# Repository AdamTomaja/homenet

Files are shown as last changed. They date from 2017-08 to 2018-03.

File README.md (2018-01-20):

# Home-Net
What is Home-Net? Home-Net is a project which will make Your Home Smart :) 
With Home-Net You can script Your devices in JavaScript and Control them from WEB.

# Screenshots
## Home-Net: Main Page
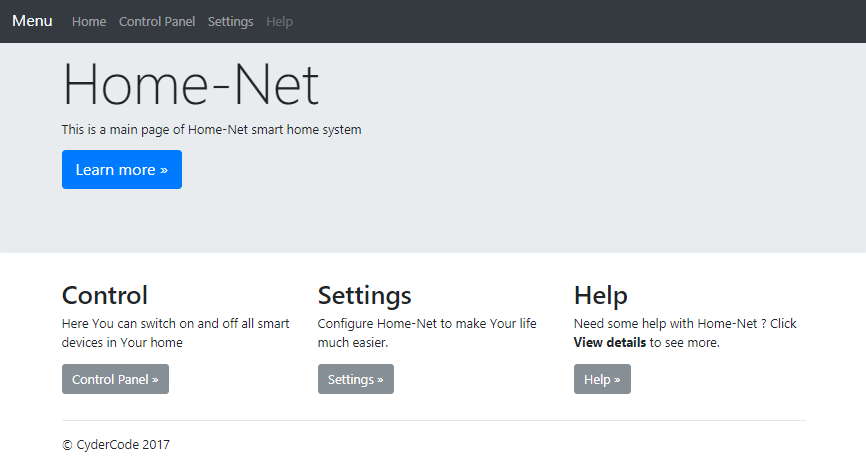
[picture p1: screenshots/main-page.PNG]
Main Page Home-Net Landing Page


## Home-Net: Control Panel
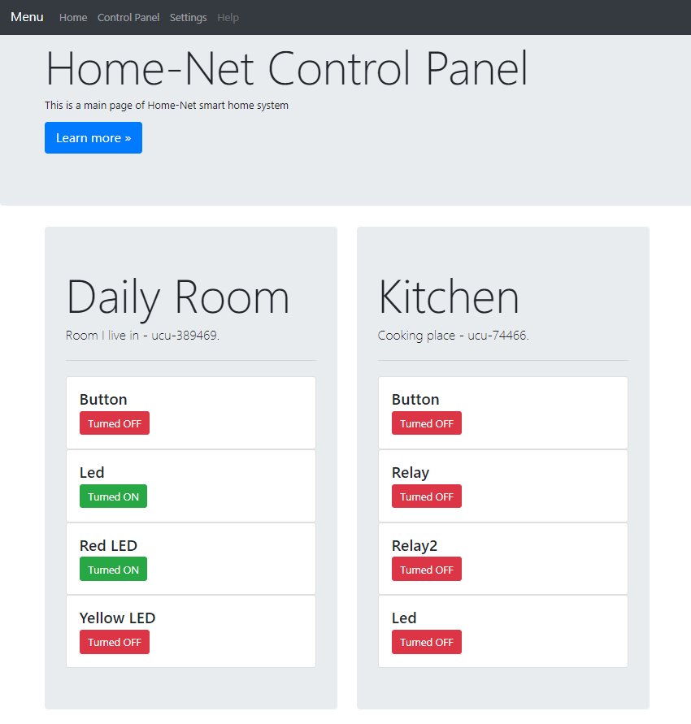
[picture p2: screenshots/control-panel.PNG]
Main Page Home-Net Control Panel


# Configuring system and running UMU
## Network Configuration
MQTT Broker has to be configured with static IP.
To do this, please reconfigure Your /etc/dhcpcd.conf file as follows:

```bash
interface wlan0
static ip_address 192.168.0.10/24
static routers=192.168.0.1
static domain_name_servers=127.0.0.1 8.8.8.8 8.8.4.4
```

## TimeZone Configuration
Please remember to set Your timezone on Linux where UMU is installed. 
This is important because You can use time in Javascript flows. 
For example hour is used to determine if turn lights on when motion is detected.

```bash
sudo dpkg-reconfigure tzdata
```

## Start MQTT broker
Please a compatible MQTT broker for the homenet infrastructure. 
I suggest to use Mosquitto. 
You can run install it and run using following command: 

```bash
service mosquitto start
```

## Install Grafana and Influx DB
* Install InfluxDB
```bash
apt-get install influxdb
```

* Check the status of grafana service
```bash
service influxd status
```
You can also open web interface of influxdb: **http://host:8083**

* Install and start the Grafana
```bash
apt-get install grafana
service grafana-server start
```

* Check the status of Grafana **http://host:3000**

## Run UMU server
Execute following command in **homenet-server** directory
```bash
maven spring-boot:run
```

# MQTT Topics
This is description of MQTT topics used by HomeNet UCU and UMU. 

| Topic name | Description | Message class |
|---|---|---|
| /ucu/gpio/configure | configure gpio direction, input output pullup | ConfigureGpioMessage |
| /ucu/gpio/set | set value for gpio on ucu | SetGpioValueMessage  |
| /umu/gpio/set | gpio value changed on ucu | SetGpioValueMessage  |
| /ucu/hello | request to all ucus to send message to umu with instance names | HelloMessage |
| /umu/hello | all ucus can introduce themselfs to umu | HelloMessage |
| /umu/error | ucu sends to this topic information about errors | ErrorMessage |
| /umu/ping | ucus sends ping message as answer for ping message from umu | PingMessage |
| /ucu/ping | umu send ping request to all ucus | PingMessage |

# UCU Connector
| Signal | Wire Color | Connector Pin |
|---|---|---|
| 5V | Red | 1 |
| 3.3V | White | 2 |
| IO | Blue | 3 |
| GND | Black | 4 |

# LCU - Light Control Unit - Specification
* One 230V Relay output
* Integrated 5V Power Supply
* External Reset Button - in case of BUGs in software
* External MicroUSB port - for programming
* Fixed to wall like normal light switch - using metal frame from common light switch
* External BLS 2x2 Ports for additional sensors and devices `(GND, 5V, 3.3V, GPIO)`
* Fallback to direct power to light

### NodeMCU Pin Capabilities
| IO Index  | Esp8266 pin | OUTPUT | INPUT | Function |
|---|---  |---|---|---|
| 0 | Gpio16 | X | --- (USER Led) | Notification LED  |
| 1 | Gpio5 | X | X | IO0 |
| 2 | Gpio4 | X | X | IO1 |
| 3 | Gpio0 | X | X (Flash Button)  | IO2 | 
| 4 | Gpio2 | X | X | IO3 |
| 5 | Gpio14 | X | X | IO4 | 
| 6 | Gpio12 | X | X | IO5 |
| 7 | Gpio13 | X | X | IO6 |
| 8 | Gpio15 | X | X/2 BOOT,NOPULLUP | Relay |
| 11 - SD2  | Gpio9 | X | X | Button A |
| 12 - SD3  | Gpio10 | X | X | Button B |
| A0 | ADC0 | --- | --- | IO8 |

# UMU Configuration
```json
{
  "mqtt": {
    "host": "rpi-umu",
    "port": 1883
  },
  "instances": [
    {
      "id": "ucu-389469",
      "name": "Daily Room",
      "description": "Room I live in",
      "gpios": [
        {
          "name": "Button",
          "mode": "INPUT",
          "isPullup": true,
          "pin": 3,
          "invert": true
        },
        {
          "name": "Led",
          "mode": "OUTPUT",
          "isPullup": false,
          "pin": 4,
          "initialValue": 1,
          "invert": true
        }
      ]
    }
  ]
}
```

## HomeLets
Homelets are small Javascript application which are used to add some logic to Your home behavior. 
The api is very is simple and similar to Arduino. You have setup method and loop. 
It`s possible to add listeners for given control unit and gpio. Also it``s possible last known value of gpio or set new value of output. 

This is example homelet, responsible for turning  on the light when motion is detected or turning off when no  motion detected for 15 minutes.

```javascript
/** Consts **/
var adamsRoom = "Adam Room";
var lightRelay = "Light Relay";
var motionSensor = "Motion Sensor";

var LIGHTS_OFF_TIMEOUT = 15 * 60;

/* Global Variables */
var lastMovementTime = 0;

/* Methods */
function getTimestamp() {
    return new Date().getTime();
}

function getHours() {
    return new Date().getHours();
}

setup = function() {
    this.addListener(adamsRoom, motionSensor, function(value) {
        if(value) {
            var hour = getHours();
            if(hour >= 18 && hour <= 22) {
                this.setValue(adamsRoom, lightRelay, 0);
            }
        }
    });
}

loop = function() {

    var motionSensorValue = this.getValue(adamsRoom, motionSensor);
    var currentTimestamp = getTimestamp();

    if(motionSensorValue) {
        lastMovementTime = currentTimestamp;
    }

    var secondsElapsed = (currentTimestamp - lastMovementTime) / 1000;
    if(secondsElapsed > LIGHTS_OFF_TIMEOUT) {
        this.setValue(adamsRoom, lightRelay, 1);
    }
}
```

# UCU Configuration
Every UCU has embedded configuration server service. 

It exposes WIFI Access Point with Http server. AP will be automatically disabled after 60 seconds after boot time.
Name of AP is the same as chipid (instanceId). 

To configure UCU You should connect with UCU with WiFi and send following http request:
## UCU Configuration Http Request
* host: `192.168.4.1`
* port: `80`
* method: `POST`
* path: `/`
* headers:
    * **ssid** - wifi SSID
    * **password** - wifi PASSWORD
    * **mqtt-host** - MQTT Broker Host
    * **mqtt-port** - MQTT Broker Port

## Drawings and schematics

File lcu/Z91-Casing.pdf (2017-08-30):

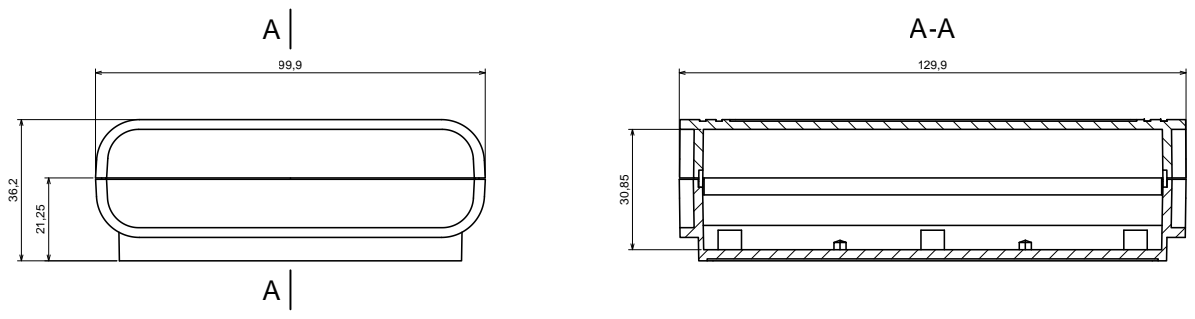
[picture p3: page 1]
Product model Format: A3 Scale 1:1; Tolerance: +/- 0.5 Material: PS, ABS Enclosure Z91 - assembly All rights reserved, Copyright Kradex 2016 AA

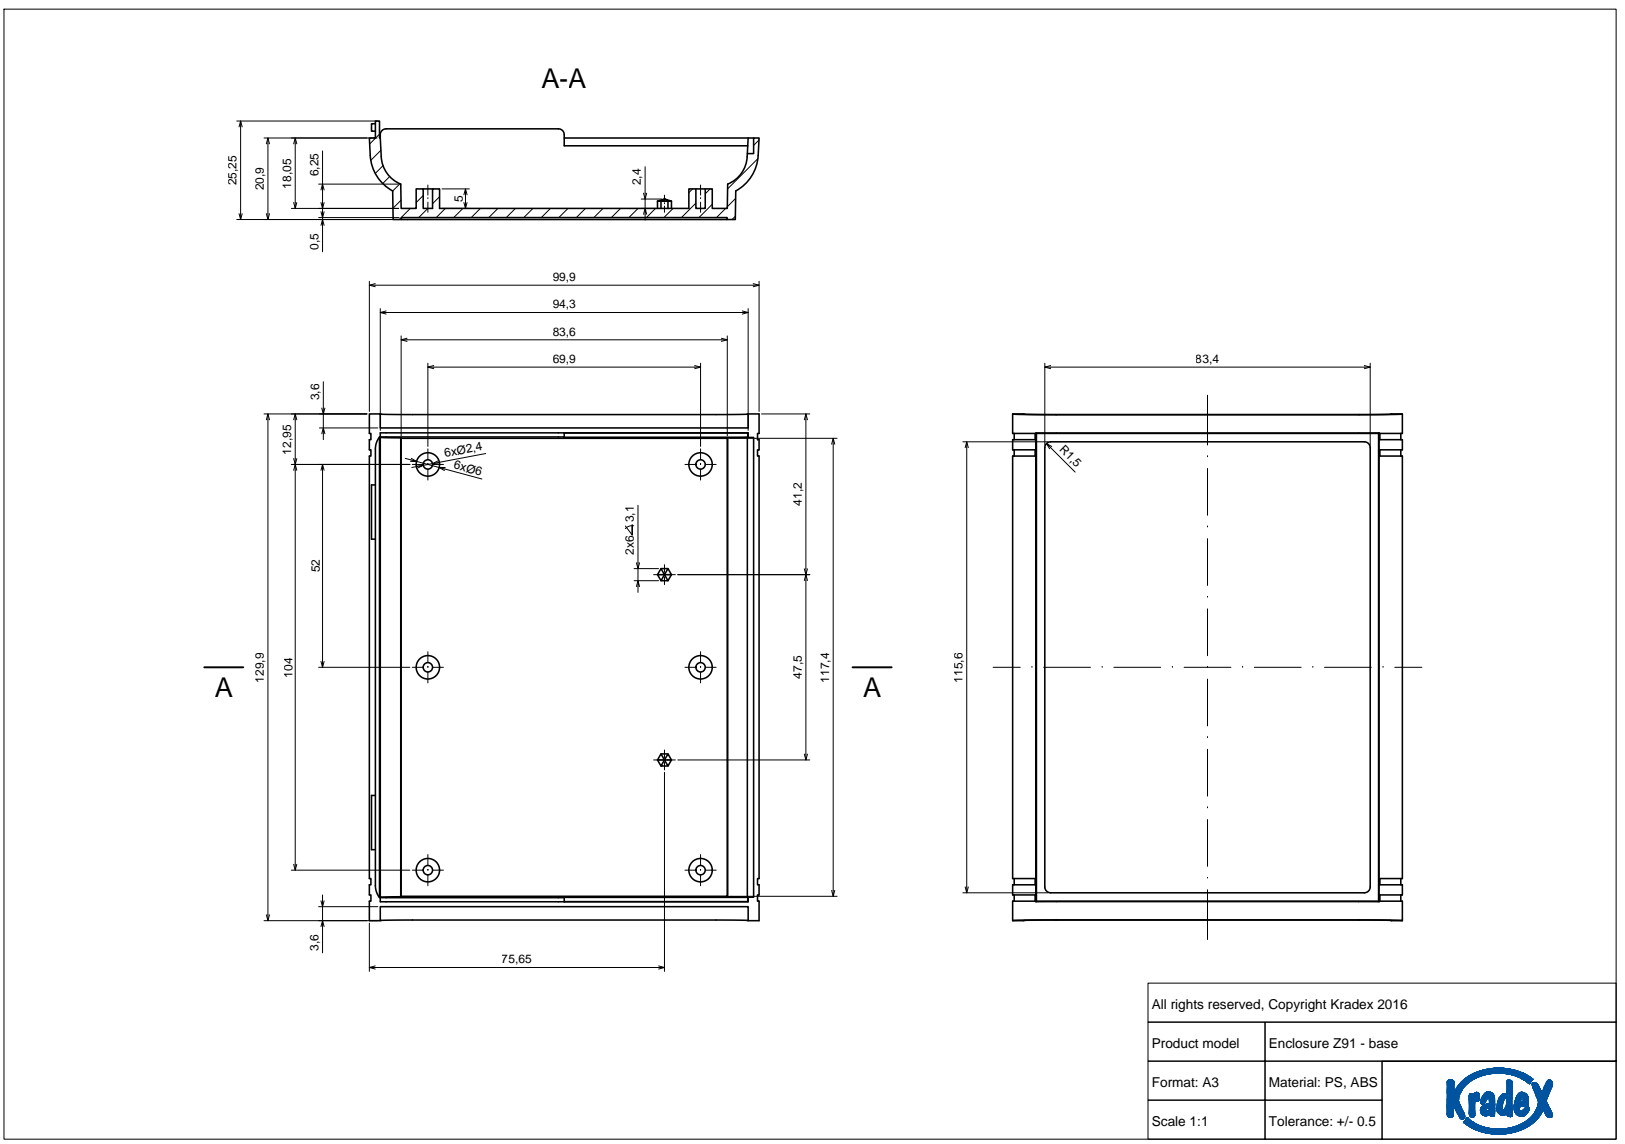
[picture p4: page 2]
Product model Format: A3 Scale 1:1; Tolerance: +/- 0.5 Material: PS, ABS Enclosure Z91 - base All rights reserved, Copyright Kradex 2016 A

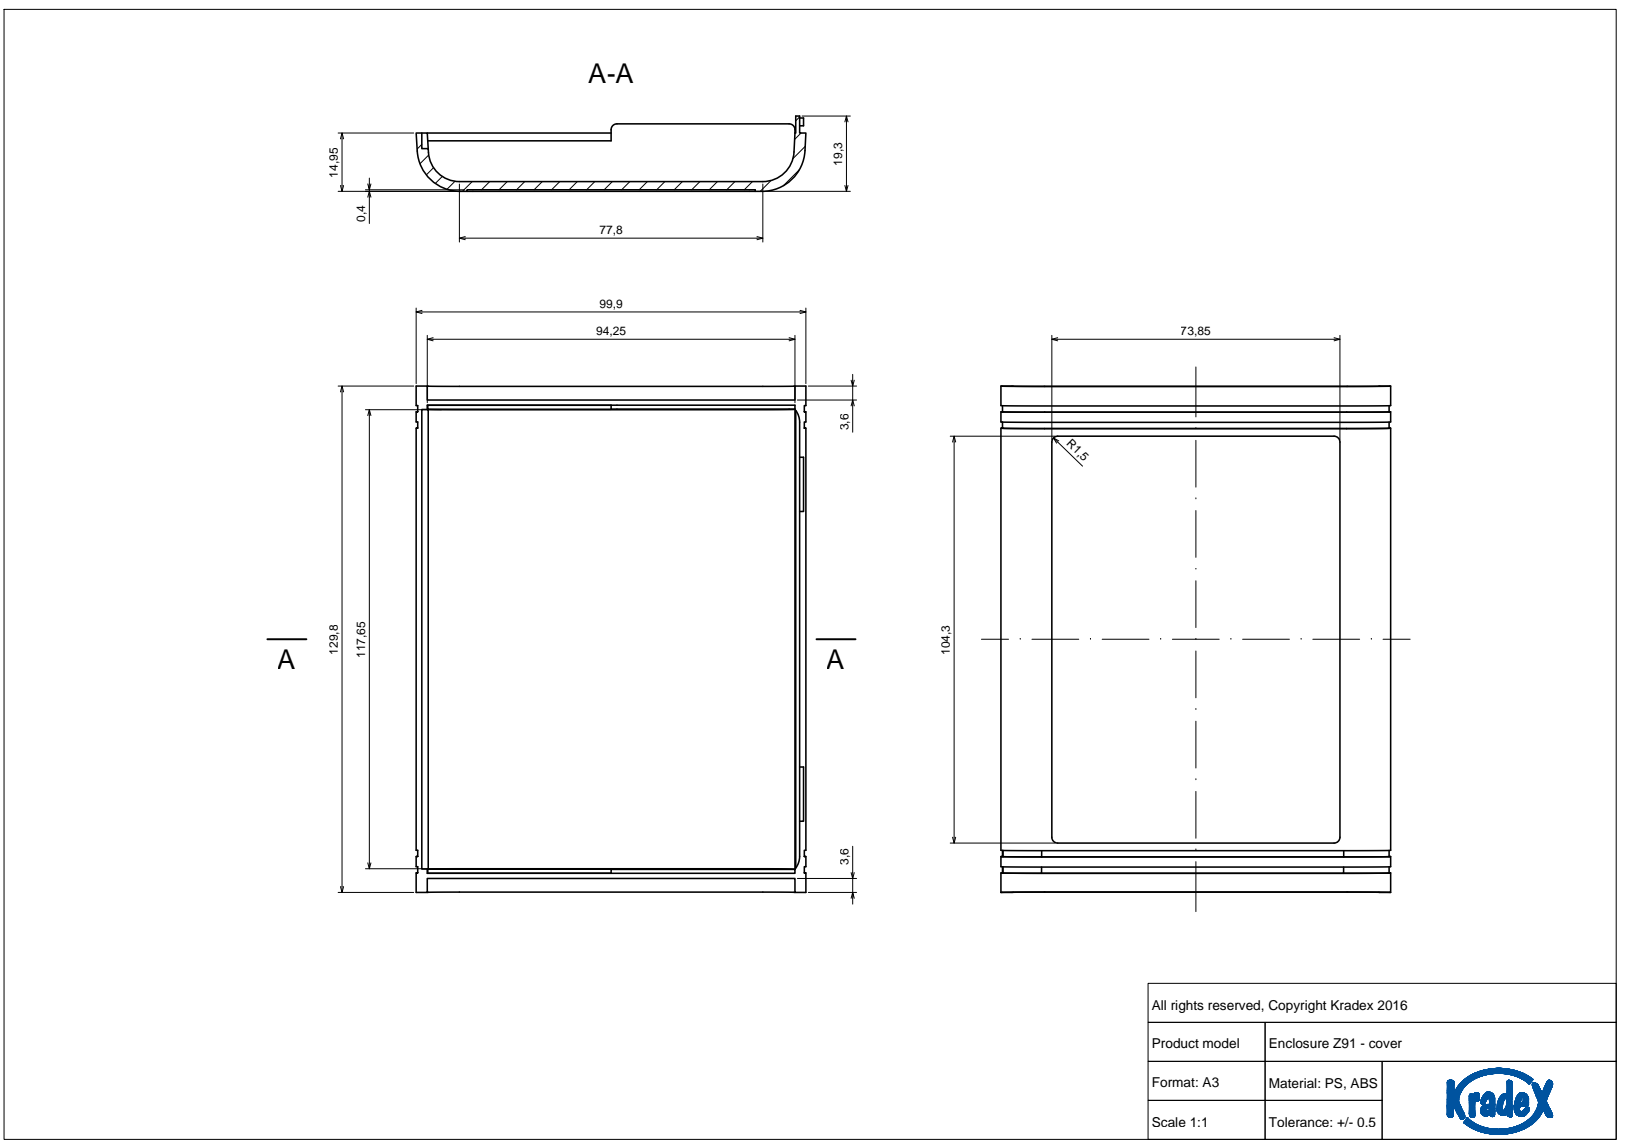
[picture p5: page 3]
Product model Format: A3 Scale 1:1; Tolerance: +/- 0.5 Material: PS, ABS Enclosure Z91 - cover All rights reserved, Copyright Kradex 2016 A

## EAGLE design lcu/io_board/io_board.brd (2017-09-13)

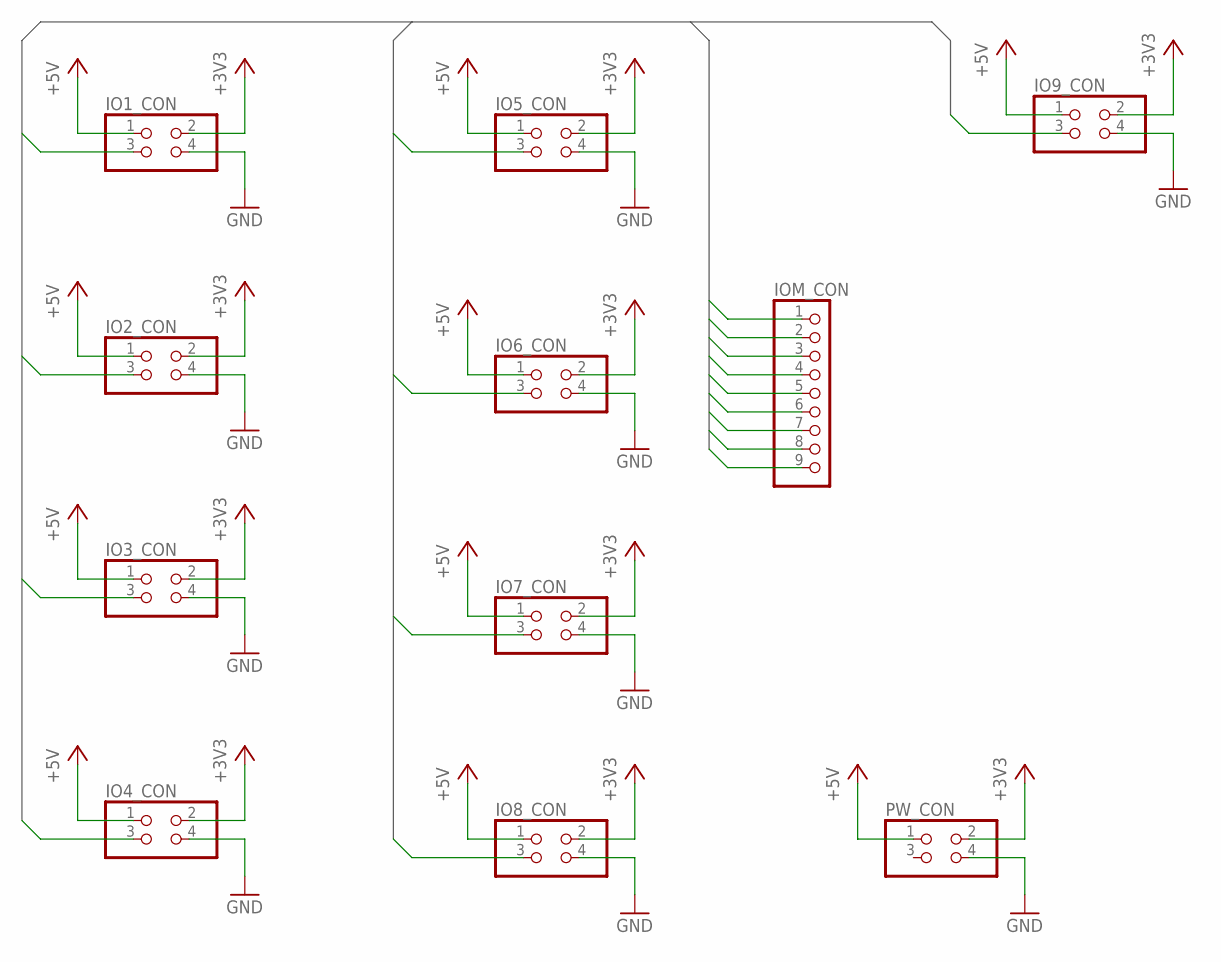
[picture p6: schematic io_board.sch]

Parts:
IO1_CON, IO2_CON, IO3_CON, IO4_CON, IO5_CON, IO6_CON, IO7_CON, IO8_CON, IO9_CON: PINHD-2X2; 2X02
IOM_CON: PINHD-1X9; 1X09
PW_CON: PINHD-2X2; 2X02

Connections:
+3V3: IO1_CON.2, IO2_CON.2, IO3_CON.2, IO4_CON.2, IO5_CON.2, IO6_CON.2, IO7_CON.2, IO8_CON.2, IO9_CON.2, PW_CON.2
+5V: IO1_CON.1, IO2_CON.1, IO3_CON.1, IO4_CON.1, IO5_CON.1, IO6_CON.1, IO7_CON.1, IO8_CON.1, IO9_CON.1, PW_CON.1
GND: IO1_CON.4, IO2_CON.4, IO3_CON.4, IO4_CON.4, IO5_CON.4, IO6_CON.4, IO7_CON.4, IO8_CON.4, IO9_CON.4, PW_CON.4
IO0: IO1_CON.3, IOM_CON.1
IO1: IO2_CON.3, IOM_CON.2
IO2: IO3_CON.3, IOM_CON.3
IO3: IO4_CON.3, IOM_CON.4
IO4: IO5_CON.3, IOM_CON.5
IO5: IO6_CON.3, IOM_CON.6
IO6: IO7_CON.3, IOM_CON.7
IO7: IO8_CON.3, IOM_CON.8
IO8: IO9_CON.3, IOM_CON.9

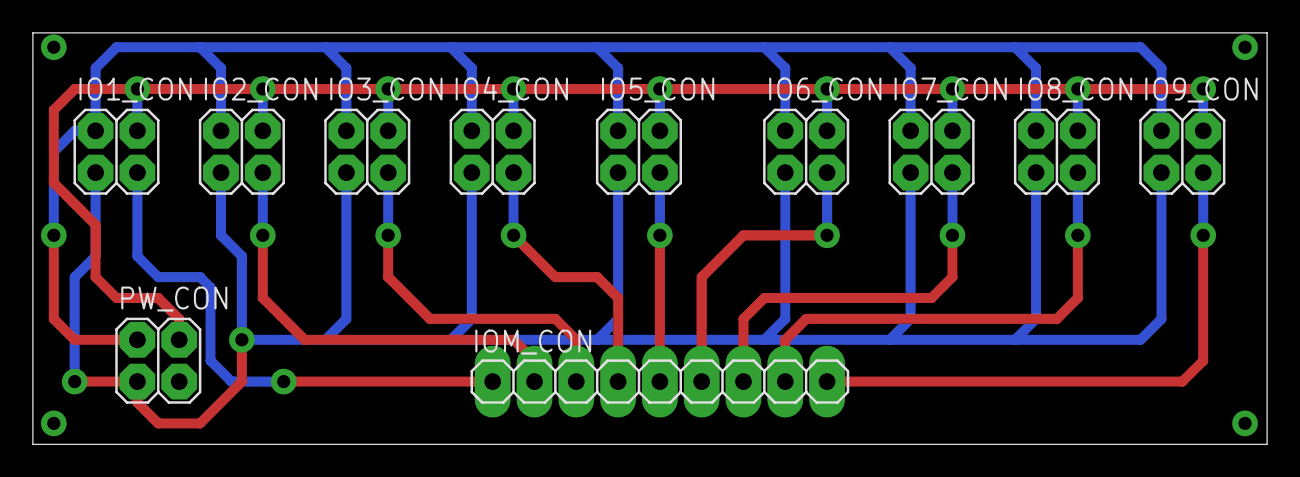
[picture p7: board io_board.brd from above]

Board: 2 copper layers, 75.0 x 25.0 mm, 11 parts (0 on the bottom side), 12 nets.

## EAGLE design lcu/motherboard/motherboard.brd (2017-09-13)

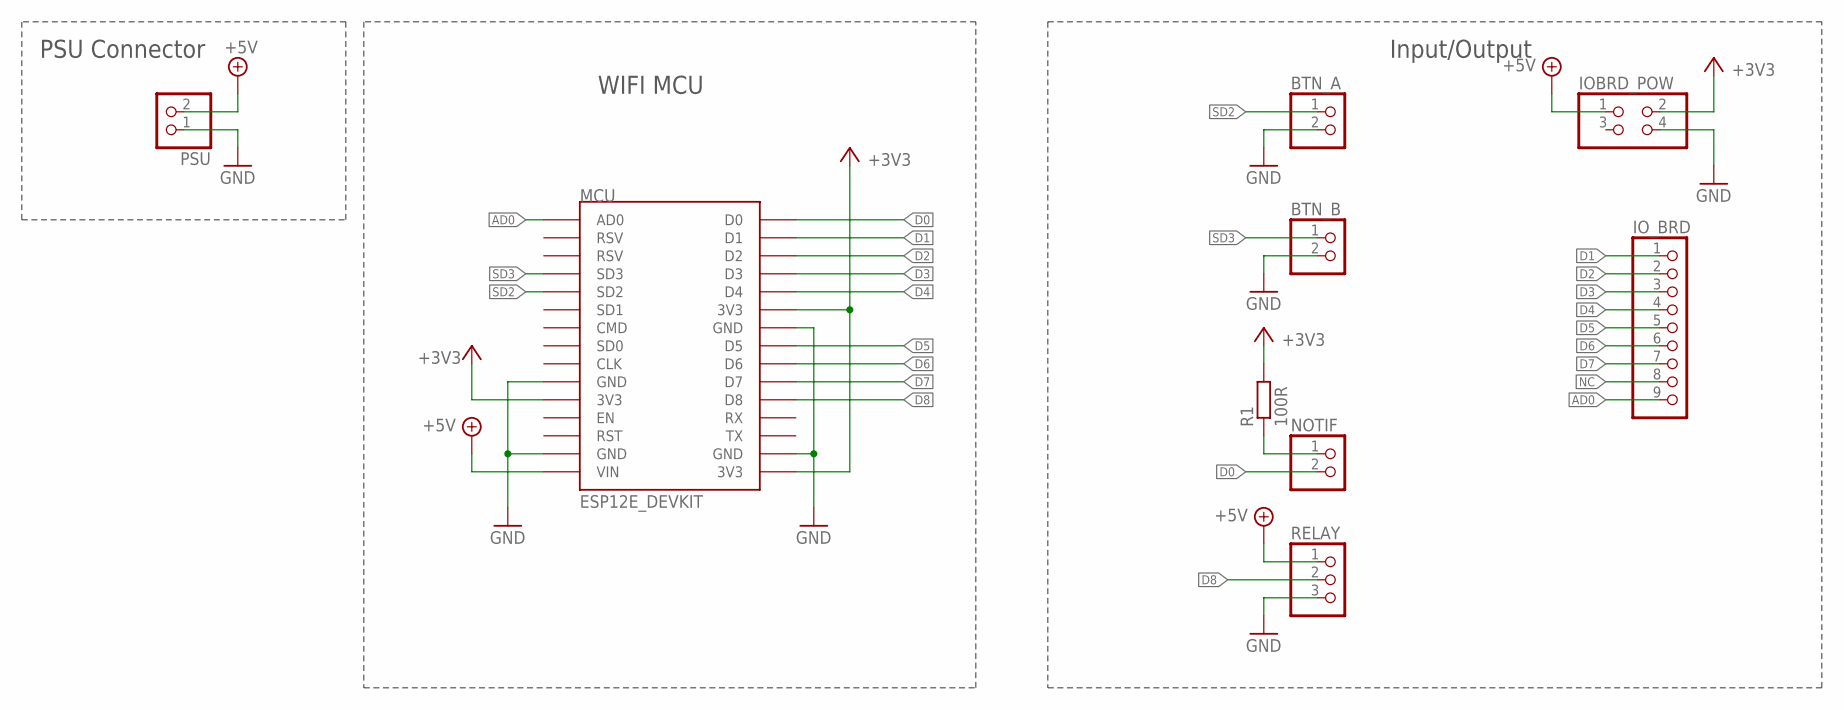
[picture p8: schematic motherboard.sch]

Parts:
BTN_A: PINHD-1X2; 1X02
BTN_B: PINHD-1X2; 1X02
IOBRD_POW: PINHD-2X2; 2X02
IO_BRD: PINHD-1X9; 1X09
MCU: ESP12E_DEVKIT
NOTIF: PINHD-1X2; 1X02
PSU: PINHD-1X2; 1X02
R1: 100R; 0204/7
RELAY: PINHD-1X3; 1X03

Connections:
+3V3: IOBRD_POW.2, MCU.3V3@0 (3V3), MCU.3V3@1 (3V3), MCU.3V3@2 (3V3), R1.2
+5V: IOBRD_POW.1, MCU.VIN, PSU.2, RELAY.1
AD0: IO_BRD.9, MCU.AD0
D0: MCU.D0, NOTIF.2
D1: IO_BRD.1, MCU.D1
D2: IO_BRD.2, MCU.D2
D3: IO_BRD.3, MCU.D3
D4: IO_BRD.4, MCU.D4
D5: IO_BRD.5, MCU.D5
D6: IO_BRD.6, MCU.D6
D7: IO_BRD.7, MCU.D7
D8: MCU.D8, RELAY.2
GND: BTN_A.2, BTN_B.2, IOBRD_POW.4, MCU.GND@0 (GND), MCU.GND@1 (GND), MCU.GND@2 (GND), MCU.GND@3 (GND), PSU.1, RELAY.3
unnamed: NOTIF.1, R1.1
NC: IO_BRD.8
SD2: BTN_A.1, MCU.SD2
SD3: BTN_B.1, MCU.SD3

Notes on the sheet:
PSU Connector
Input/Output
WIFI MCU

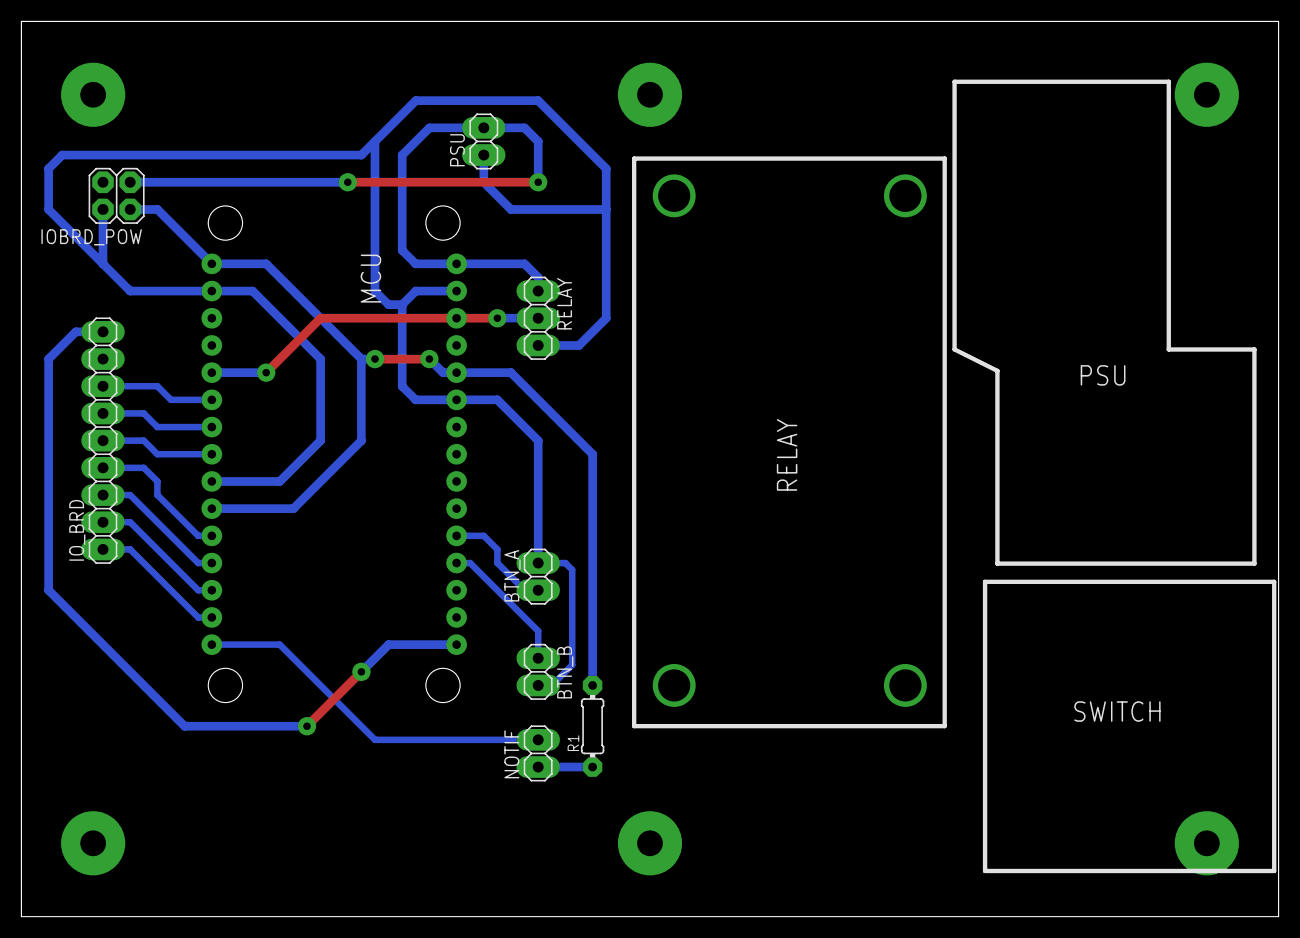
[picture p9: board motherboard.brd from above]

Board: 2 copper layers, 117.4 x 83.6 mm, 9 parts (0 on the bottom side), 16 nets.

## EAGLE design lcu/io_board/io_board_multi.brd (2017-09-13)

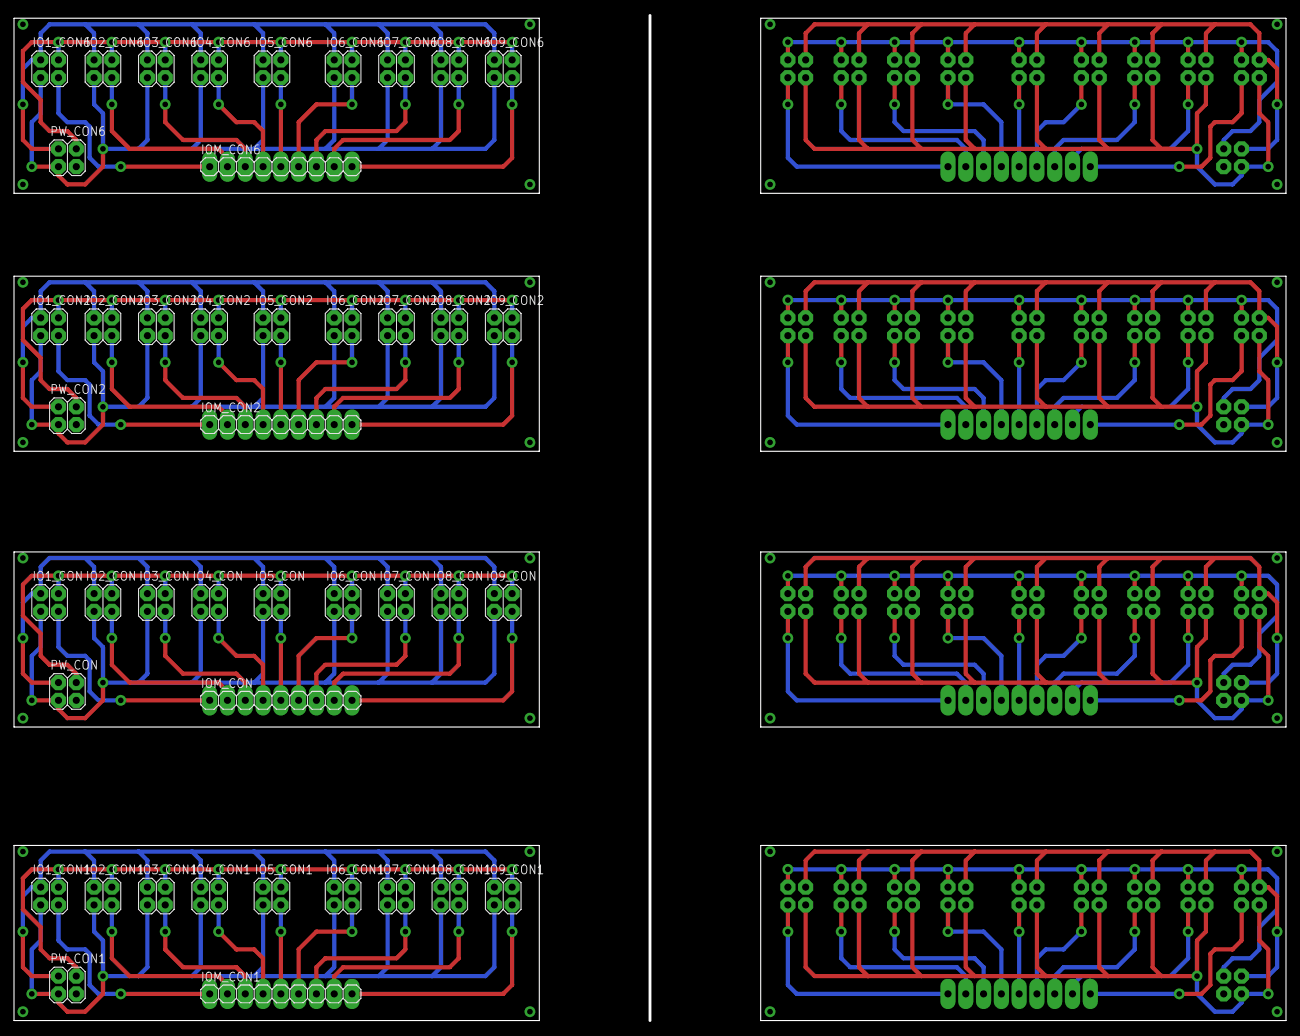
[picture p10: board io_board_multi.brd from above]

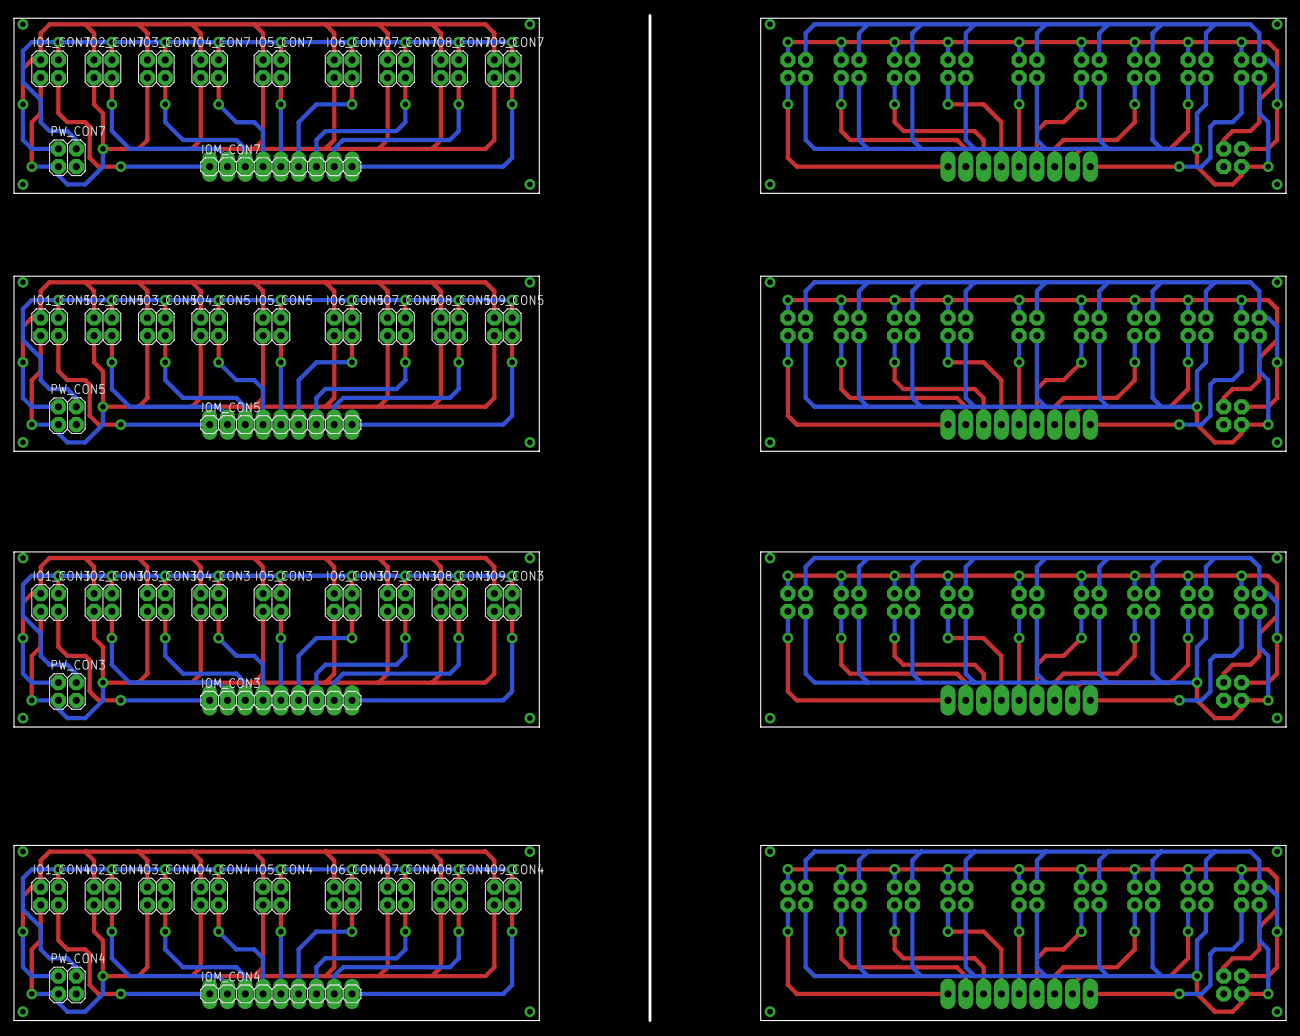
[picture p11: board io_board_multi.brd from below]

Board: 2 copper layers, 181.6 x 143.5 mm, 88 parts (44 on the bottom side), 96 nets.

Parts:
IO1_CON, IO1_CON1, IO1_CON2, IO1_CON3, IO1_CON4, IO1_CON5, IO1_CON6, IO1_CON7, IO2_CON, IO2_CON1, IO2_CON2, IO2_CON3, IO2_CON4, IO2_CON5, IO2_CON6, IO2_CON7, IO3_CON, IO3_CON1, IO3_CON2, IO3_CON3, IO3_CON4, IO3_CON5, IO3_CON6, IO3_CON7, IO4_CON, IO4_CON1, IO4_CON2, IO4_CON3, IO4_CON4, IO4_CON5, IO4_CON6, IO4_CON7, IO5_CON, IO5_CON1, IO5_CON2, IO5_CON3, IO5_CON4, IO5_CON5, IO5_CON6, IO5_CON7, IO6_CON, IO6_CON1, IO6_CON2, IO6_CON3, IO6_CON4, IO6_CON5, IO6_CON6, IO6_CON7, IO7_CON, IO7_CON1, IO7_CON2, IO7_CON3, IO7_CON4, IO7_CON5, IO7_CON6, IO7_CON7, IO8_CON, IO8_CON1, IO8_CON2, IO8_CON3, IO8_CON4, IO8_CON5, IO8_CON6, IO8_CON7, IO9_CON, IO9_CON1, IO9_CON2, IO9_CON3, IO9_CON4, IO9_CON5, IO9_CON6, IO9_CON7: 2X02
IOM_CON, IOM_CON1, IOM_CON2, IOM_CON3, IOM_CON4, IOM_CON5, IOM_CON6, IOM_CON7: 1X09
PW_CON, PW_CON1, PW_CON2, PW_CON3, PW_CON4, PW_CON5, PW_CON6, PW_CON7: 2X02

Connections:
+3V1: IO1_CON1.2, IO2_CON1.2, IO3_CON1.2, IO4_CON1.2, IO5_CON1.2, IO6_CON1.2, IO7_CON1.2, IO8_CON1.2, IO9_CON1.2, PW_CON1.2
+3V2: IO1_CON2.2, IO2_CON2.2, IO3_CON2.2, IO4_CON2.2, IO5_CON2.2, IO6_CON2.2, IO7_CON2.2, IO8_CON2.2, IO9_CON2.2, PW_CON2.2
+3V3: IO1_CON.2, IO2_CON.2, IO3_CON.2, IO4_CON.2, IO5_CON.2, IO6_CON.2, IO7_CON.2, IO8_CON.2, IO9_CON.2, PW_CON.2
+3V4: IO1_CON3.2, IO2_CON3.2, IO3_CON3.2, IO4_CON3.2, IO5_CON3.2, IO6_CON3.2, IO7_CON3.2, IO8_CON3.2, IO9_CON3.2, PW_CON3.2
+3V5: IO1_CON4.2, IO2_CON4.2, IO3_CON4.2, IO4_CON4.2, IO5_CON4.2, IO6_CON4.2, IO7_CON4.2, IO8_CON4.2, IO9_CON4.2, PW_CON4.2
+3V6: IO1_CON5.2, IO2_CON5.2, IO3_CON5.2, IO4_CON5.2, IO5_CON5.2, IO6_CON5.2, IO7_CON5.2, IO8_CON5.2, IO9_CON5.2, PW_CON5.2
+3V7: IO1_CON6.2, IO2_CON6.2, IO3_CON6.2, IO4_CON6.2, IO5_CON6.2, IO6_CON6.2, IO7_CON6.2, IO8_CON6.2, IO9_CON6.2, PW_CON6.2
+3V8: IO1_CON7.2, IO2_CON7.2, IO3_CON7.2, IO4_CON7.2, IO5_CON7.2, IO6_CON7.2, IO7_CON7.2, IO8_CON7.2, IO9_CON7.2, PW_CON7.2
+5V: IO1_CON.1, IO2_CON.1, IO3_CON.1, IO4_CON.1, IO5_CON.1, IO6_CON.1, IO7_CON.1, IO8_CON.1, IO9_CON.1, PW_CON.1
+5V1: IO1_CON1.1, IO2_CON1.1, IO3_CON1.1, IO4_CON1.1, IO5_CON1.1, IO6_CON1.1, IO7_CON1.1, IO8_CON1.1, IO9_CON1.1, PW_CON1.1
+5V2: IO1_CON2.1, IO2_CON2.1, IO3_CON2.1, IO4_CON2.1, IO5_CON2.1, IO6_CON2.1, IO7_CON2.1, IO8_CON2.1, IO9_CON2.1, PW_CON2.1
+5V3: IO1_CON3.1, IO2_CON3.1, IO3_CON3.1, IO4_CON3.1, IO5_CON3.1, IO6_CON3.1, IO7_CON3.1, IO8_CON3.1, IO9_CON3.1, PW_CON3.1
+5V4: IO1_CON4.1, IO2_CON4.1, IO3_CON4.1, IO4_CON4.1, IO5_CON4.1, IO6_CON4.1, IO7_CON4.1, IO8_CON4.1, IO9_CON4.1, PW_CON4.1
+5V5: IO1_CON5.1, IO2_CON5.1, IO3_CON5.1, IO4_CON5.1, IO5_CON5.1, IO6_CON5.1, IO7_CON5.1, IO8_CON5.1, IO9_CON5.1, PW_CON5.1
+5V6: IO1_CON6.1, IO2_CON6.1, IO3_CON6.1, IO4_CON6.1, IO5_CON6.1, IO6_CON6.1, IO7_CON6.1, IO8_CON6.1, IO9_CON6.1, PW_CON6.1
+5V7: IO1_CON7.1, IO2_CON7.1, IO3_CON7.1, IO4_CON7.1, IO5_CON7.1, IO6_CON7.1, IO7_CON7.1, IO8_CON7.1, IO9_CON7.1, PW_CON7.1
GND: IO1_CON.4, IO2_CON.4, IO3_CON.4, IO4_CON.4, IO5_CON.4, IO6_CON.4, IO7_CON.4, IO8_CON.4, IO9_CON.4, PW_CON.4
GND1: IO1_CON1.4, IO2_CON1.4, IO3_CON1.4, IO4_CON1.4, IO5_CON1.4, IO6_CON1.4, IO7_CON1.4, IO8_CON1.4, IO9_CON1.4, PW_CON1.4
GND2: IO1_CON2.4, IO2_CON2.4, IO3_CON2.4, IO4_CON2.4, IO5_CON2.4, IO6_CON2.4, IO7_CON2.4, IO8_CON2.4, IO9_CON2.4, PW_CON2.4
GND3: IO1_CON3.4, IO2_CON3.4, IO3_CON3.4, IO4_CON3.4, IO5_CON3.4, IO6_CON3.4, IO7_CON3.4, IO8_CON3.4, IO9_CON3.4, PW_CON3.4
GND4: IO1_CON4.4, IO2_CON4.4, IO3_CON4.4, IO4_CON4.4, IO5_CON4.4, IO6_CON4.4, IO7_CON4.4, IO8_CON4.4, IO9_CON4.4, PW_CON4.4
GND5: IO1_CON5.4, IO2_CON5.4, IO3_CON5.4, IO4_CON5.4, IO5_CON5.4, IO6_CON5.4, IO7_CON5.4, IO8_CON5.4, IO9_CON5.4, PW_CON5.4
GND6: IO1_CON6.4, IO2_CON6.4, IO3_CON6.4, IO4_CON6.4, IO5_CON6.4, IO6_CON6.4, IO7_CON6.4, IO8_CON6.4, IO9_CON6.4, PW_CON6.4
GND7: IO1_CON7.4, IO2_CON7.4, IO3_CON7.4, IO4_CON7.4, IO5_CON7.4, IO6_CON7.4, IO7_CON7.4, IO8_CON7.4, IO9_CON7.4, PW_CON7.4
IO0: IO1_CON.3, IOM_CON.1
IO1: IO2_CON.3, IOM_CON.2
IO2: IO3_CON.3, IOM_CON.3
IO3: IO4_CON.3, IOM_CON.4
IO4: IO5_CON.3, IOM_CON.5
IO5: IO6_CON.3, IOM_CON.6
IO6: IO7_CON.3, IOM_CON.7
IO7: IO8_CON.3, IOM_CON.8
IO8: IO9_CON.3, IOM_CON.9
IO9: IO8_CON1.3, IOM_CON1.8
IO10: IO7_CON1.3, IOM_CON1.7
IO11: IO6_CON1.3, IOM_CON1.6
IO12: IO5_CON1.3, IOM_CON1.5
IO13: IO4_CON1.3, IOM_CON1.4
IO14: IO3_CON1.3, IOM_CON1.3
IO15: IO2_CON1.3, IOM_CON1.2
IO16: IO1_CON1.3, IOM_CON1.1
IO17: IO9_CON1.3, IOM_CON1.9
IO18: IO8_CON2.3, IOM_CON2.8
IO19: IO7_CON2.3, IOM_CON2.7
IO20: IO6_CON2.3, IOM_CON2.6
IO21: IO5_CON2.3, IOM_CON2.5
IO22: IO4_CON2.3, IOM_CON2.4
IO23: IO3_CON2.3, IOM_CON2.3
IO24: IO2_CON2.3, IOM_CON2.2
IO25: IO1_CON2.3, IOM_CON2.1
IO26: IO9_CON2.3, IOM_CON2.9
IO27: IO8_CON3.3, IOM_CON3.8
IO28: IO7_CON3.3, IOM_CON3.7
IO29: IO6_CON3.3, IOM_CON3.6
IO30: IO5_CON3.3, IOM_CON3.5
IO31: IO4_CON3.3, IOM_CON3.4
IO32: IO3_CON3.3, IOM_CON3.3
IO33: IO2_CON3.3, IOM_CON3.2
IO34: IO1_CON3.3, IOM_CON3.1
IO35: IO9_CON3.3, IOM_CON3.9
IO36: IO8_CON4.3, IOM_CON4.8
IO37: IO7_CON4.3, IOM_CON4.7
IO38: IO6_CON4.3, IOM_CON4.6
IO39: IO5_CON4.3, IOM_CON4.5
IO40: IO4_CON4.3, IOM_CON4.4
IO41: IO3_CON4.3, IOM_CON4.3
IO42: IO2_CON4.3, IOM_CON4.2
IO43: IO1_CON4.3, IOM_CON4.1
IO44: IO9_CON4.3, IOM_CON4.9
IO45: IO8_CON5.3, IOM_CON5.8
IO46: IO7_CON5.3, IOM_CON5.7
IO47: IO6_CON5.3, IOM_CON5.6
IO48: IO5_CON5.3, IOM_CON5.5
IO49: IO4_CON5.3, IOM_CON5.4
IO50: IO3_CON5.3, IOM_CON5.3
IO51: IO2_CON5.3, IOM_CON5.2
IO52: IO1_CON5.3, IOM_CON5.1
IO53: IO9_CON5.3, IOM_CON5.9
IO54: IO8_CON6.3, IOM_CON6.8
IO55: IO7_CON6.3, IOM_CON6.7
IO56: IO6_CON6.3, IOM_CON6.6
IO57: IO5_CON6.3, IOM_CON6.5
IO58: IO4_CON6.3, IOM_CON6.4
IO59: IO3_CON6.3, IOM_CON6.3
IO60: IO2_CON6.3, IOM_CON6.2
IO61: IO1_CON6.3, IOM_CON6.1
IO62: IO9_CON6.3, IOM_CON6.9
IO63: IO8_CON7.3, IOM_CON7.8
IO64: IO7_CON7.3, IOM_CON7.7
IO65: IO6_CON7.3, IOM_CON7.6
IO66: IO5_CON7.3, IOM_CON7.5
IO67: IO4_CON7.3, IOM_CON7.4
IO68: IO3_CON7.3, IOM_CON7.3
IO69: IO2_CON7.3, IOM_CON7.2
IO70: IO1_CON7.3, IOM_CON7.1
IO71: IO9_CON7.3, IOM_CON7.9

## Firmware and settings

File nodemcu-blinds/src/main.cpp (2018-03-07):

#include <Arduino.h>
#include <ESP8266WiFi.h>
#include <PubSubClient.h>

/** Node configuration **/
const char* SSID = "<SSID>";
const char* PASSWORD = "<PASSWORD>";
const char* MQTT_SERVER = "192.168.1.10";
const char* MQTT_USERNAME = "yourMQTTusername";
const char* MQTT_PASSWORD = "yourMQTTpassword";
const int   MQTT_PORT = 1883;

/** MQTT Constant **/
const char* NODE_NAME = "adamRoomWindowShutter";
const char* SET_TOPIC = "cmnd/adamRoomWindowShutter";
const char* STATUS_TOPIC = "stat/adamRoomWindowShutter/status";
const char* UP_MESSAGE = "UP";
const char* DOWN_MESSAGE = "DOWN";
const char* STOP_MESSAGE = "STOP";

/** PINOUT **/
const int   DIRECTION_PIN = 14;
const int   POWER_PIN     = 4;

/** Internal **/
const int ON = 0;
const int OFF = 1;

/** Timing **/
const unsigned long FULL_MOVEMENT_TIME = 40 * 1000;

unsigned long lastCommandTime = 0;
bool stateModified = false;

WiFiClient espClient;
PubSubClient client(espClient);

void setupWifi();
void checkWifi();
void setupMQTT();
void checkMQTT();
void reconnectMQTT();
void callback(char* topic, byte* payload, unsigned int length);

void setup() {
  Serial.begin(115200);
  Serial.println("Starting ...");

  pinMode(POWER_PIN, OUTPUT);
  pinMode(DIRECTION_PIN, OUTPUT);
  digitalWrite(POWER_PIN, OFF);
  digitalWrite(DIRECTION_PIN, OFF);

  setupWifi();
  setupMQTT();
}

void setupWifi() {
  WiFi.mode(WIFI_STA);
  WiFi.begin(SSID, PASSWORD);

  while(WiFi.status() != WL_CONNECTED) {
    delay(500);
    Serial.print("Connecting to: ");
    Serial.println(SSID);
  }

  Serial.println("WiFi connected!");
  Serial.print("IP address: ");
  Serial.println(WiFi.localIP());
}

void markStateModified() {
  stateModified = true;
  lastCommandTime = millis();
}

void writeState(int power, int direction) {
  digitalWrite(DIRECTION_PIN, direction);
  digitalWrite(POWER_PIN, power);
  markStateModified();
}

void callback(char* topic, byte* payload, unsigned int length) {
  Serial.println("Message received");

  char message[length + 1];
  for(int i = 0; i < length; i++) {
    message[i] = (char) payload[i];
  }

  message[length] = '\0';

  String messageString = String(message);

  if(messageString == "UP") {
    writeState(ON, OFF);
    client.publish(STATUS_TOPIC, "UP");
  }

  if(messageString == "DOWN") {
    writeState(ON, ON);
    client.publish(STATUS_TOPIC, "DOWN");
  }

  if(messageString == "STOP") {
    writeState(OFF, OFF);
    client.publish(STATUS_TOPIC, "STOP");
  }

  Serial.println(message);
}

void loop() {

  checkWifi();
  if(!client.connected()) {
    Serial.println("MQTT disconnected.");
    reconnectMQTT();
  }

  client.loop();

  if(stateModified && (millis() - lastCommandTime > FULL_MOVEMENT_TIME)) {
    Serial.println("Turning off");
    digitalWrite(POWER_PIN, OFF);
    digitalWrite(DIRECTION_PIN, OFF);
    stateModified = false;
    client.publish(STATUS_TOPIC, "STOP");
  }
}

void checkWifi() {
  if (WiFi.status() != WL_CONNECTED) {
    Serial.print("WIFI Disconnected. Attempting reconnection.");
    setupWifi();
  }
}

void setupMQTT() {
  client.setServer(MQTT_SERVER, MQTT_PORT);
  client.setCallback(callback);
}

void reconnectMQTT() {
  // Loop until we're reconnected
  while (!client.connected()) {
    Serial.println("Attempting MQTT connection...");
    // Attempt to connect
    if (client.connect(NODE_NAME, MQTT_USERNAME, MQTT_PASSWORD)) {
      Serial.println("MQTT Connected");
      client.subscribe(SET_TOPIC);
      client.publish(STATUS_TOPIC,"ACTIVE");
    } else {
      Serial.print("failed, rc=");
      Serial.print(client.state());
      Serial.println(" try again in 5 seconds");
      // Wait 5 seconds before retrying
      delay(5000);
    }
  }
}

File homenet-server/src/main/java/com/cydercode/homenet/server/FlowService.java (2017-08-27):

package com.cydercode.homenet.server;

import com.cydercode.homenet.cdm.SetGpioValueMessage;
import com.cydercode.homenet.server.config.GpioConfiguration;
import com.cydercode.homenet.server.config.UcuInstance;
import com.cydercode.homenet.server.flow.FlowAPI;
import com.cydercode.homenet.server.websocket.WebSocketHandler;
import jdk.nashorn.api.scripting.ScriptObjectMirror;
import org.apache.commons.io.IOUtils;
import org.slf4j.Logger;
import org.slf4j.LoggerFactory;
import org.springframework.beans.factory.annotation.Autowired;
import org.springframework.scheduling.annotation.Scheduled;
import org.springframework.stereotype.Component;

import javax.annotation.PostConstruct;
import javax.script.ScriptEngine;
import javax.script.ScriptEngineManager;
import javax.script.ScriptException;
import java.io.IOException;
import java.util.Optional;

@Component
public class FlowService {

    private static final Logger LOGGER = LoggerFactory.getLogger(FlowService.class);

    private static final String FLOW_FILENAME = "flow.js";

    ScriptEngine scriptEngine;

    @Autowired
    private ConfigurationService configurationService;

    @Autowired
    private FlowAPI flowAPI;

    @PostConstruct
    public void init() throws IOException, ScriptException {
        String flow = IOUtils.toString(this.getClass().getClassLoader().getResourceAsStream("flow.js"), "UTF-8");
        LOGGER.info("Flow Loaded");

        scriptEngine = new ScriptEngineManager().getEngineByExtension("js");
        scriptEngine.eval(flow);
        ScriptObjectMirror scriptObjectMirror = (ScriptObjectMirror) scriptEngine.get("setup");
        scriptObjectMirror.call(flowAPI);
    }

    public void postMessage(Object message) {
        if (message instanceof SetGpioValueMessage) {
            SetGpioValueMessage setGpioValueMessage = (SetGpioValueMessage) message;
            Optional<UcuInstance> optionalUcuInstance = configurationService.getConfiguration(((SetGpioValueMessage) message).getInstanceId());
            if (optionalUcuInstance.isPresent()) {
                UcuInstance instance = optionalUcuInstance.get();
                Optional<GpioConfiguration> optionalGpio = instance.getGpioByPin(setGpioValueMessage.getPin());
                if (optionalGpio.isPresent()) {
                    GpioConfiguration gpioConfiguration = optionalGpio.get();
                    flowAPI.fireListeners(instance.getName(), gpioConfiguration.getName(), setGpioValueMessage.getValue());
                }
            } else {
                LOGGER.warn("{} ucu configuration not found, ignoring", setGpioValueMessage.getInstanceId());
            }
        } else {
            LOGGER.error("Unkown message type {}", message);
        }
    }

    @Scheduled(fixedRate = 1000)
    public void loop() {
        ((ScriptObjectMirror) scriptEngine.get("loop")).call(flowAPI);
    }
}

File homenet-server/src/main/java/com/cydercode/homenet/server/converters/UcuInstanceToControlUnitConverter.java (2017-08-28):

package com.cydercode.homenet.server.converters;

import com.cydercode.homenet.server.config.UcuInstance;
import com.cydercode.homenet.server.health.InstancesHealthService;
import com.cydercode.homenet.server.rest.ControlUnit;
import org.springframework.beans.factory.annotation.Autowired;
import org.springframework.core.convert.converter.Converter;
import org.springframework.stereotype.Component;

import static java.util.stream.Collectors.toList;

@Component
public class UcuInstanceToControlUnitConverter implements Converter<UcuInstance, ControlUnit> {

    @Autowired
    private GpioToDeviceConverter gpioToDeviceConverter;

    @Autowired
    private InstancesHealthService instancesHealthService;

    @Override
    public ControlUnit convert(UcuInstance ucuInstance) {
        ControlUnit unit = new ControlUnit();
        unit.setId(ucuInstance.getId());
        unit.setName(ucuInstance.getName());
        unit.setDescription(ucuInstance.getDescription());
        unit.setHealth(instancesHealthService.getHealth(ucuInstance));
        unit.setDevices(ucuInstance.getGpios()
                .stream()
                .map(gpioToDeviceConverter::convert)
                .collect(toList()));

        return unit;
    }
}

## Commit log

2017-08-24 Spring boot app with mqtt listening and publishing service
2017-08-27 Inverted type changed to boolean, blocking device buttons until value update not received
    [GpioConfiguration.java]
2017-08-27 Ugly static converters migrated to spring conversion service
2017-08-27 Now errors which occured in UCU are displayed in UI
    [FlowService.java, SetGpioValueMessageHandler.java, init.lua]
2017-08-27 Spring boot executable packaging
2017-08-27 Temperature measuring, adc reading
2017-08-27 Voltage reading
2017-08-30 Started to design schematics
    [motherboard.sch]
2017-08-30 Casing in eagle
    [motherboard.brd, motherboard.sch]
2017-08-30 Pre finished motherboard
    [motherboard.brd, motherboard.sch]
2017-08-31 Minor changes in LCU pcb
    [motherboard.brd, motherboard.sch]
2017-09-01 Flow for my room
2017-09-02 Motion Sensor Scheme
    [motion-sensor.sch]
2017-09-02 Motion Sensor Board
    [motion-sensor.brd]
2017-09-02 Motion Sensor Board enhacements
    [motion-sensor.sch]
2017-09-02 UCU Connector Pinout Description
2017-09-02 Favorite devices on top of control panel
2017-09-11 Motion sensor added to configuration and flow
2017-09-13 New motherboard and IOBoard
    [io_board.brd, io_board.sch, io_board_multi.brd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]
2018-01-15 RGB W2812 LED Strip
